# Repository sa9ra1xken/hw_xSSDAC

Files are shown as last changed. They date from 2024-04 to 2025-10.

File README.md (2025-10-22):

ver20230811
https://youtube.com/shorts/RJUZ4uOECH0?feature=share

This is a KiCad project for an experimental implementation of a digital audio device that features an XMOS xCORE embedded processor.
The board is intended to behave as a USB audio class output device (USB DAC), or an audio media player (Micro SD card player). 
Please refer to [project Wiki page](https://github.com/sa9ra1xken/hw_xSSDAC/wiki) for more detailed information.

# Development Environment
KiCad7.0. 

### Software project
Software (executable on xCORE-200) for this project is released here (https://github.com/sa9ra1xken/sw_xSSDAC).

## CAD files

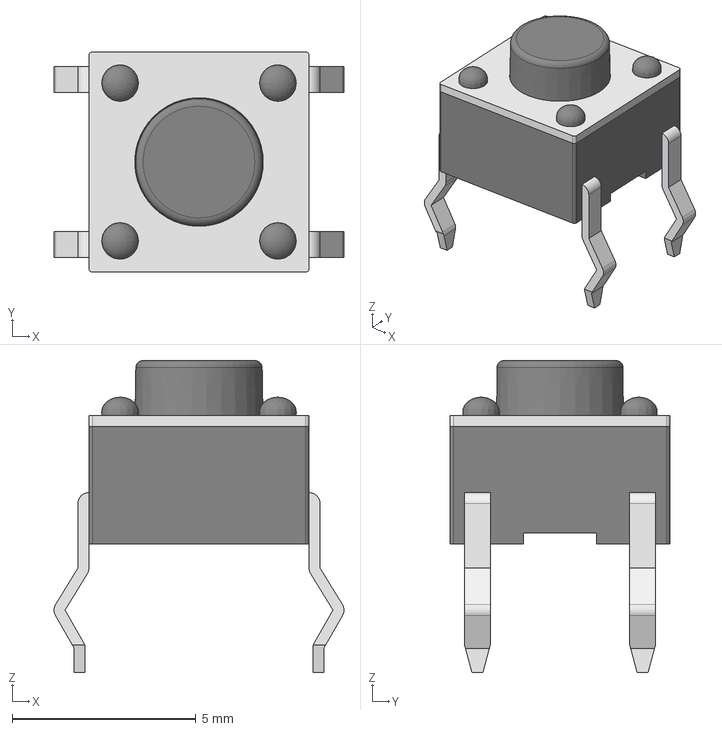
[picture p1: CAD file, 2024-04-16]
pretty/DTS-62N-V.stp
7.90 x 6.00 x 8.50 mm

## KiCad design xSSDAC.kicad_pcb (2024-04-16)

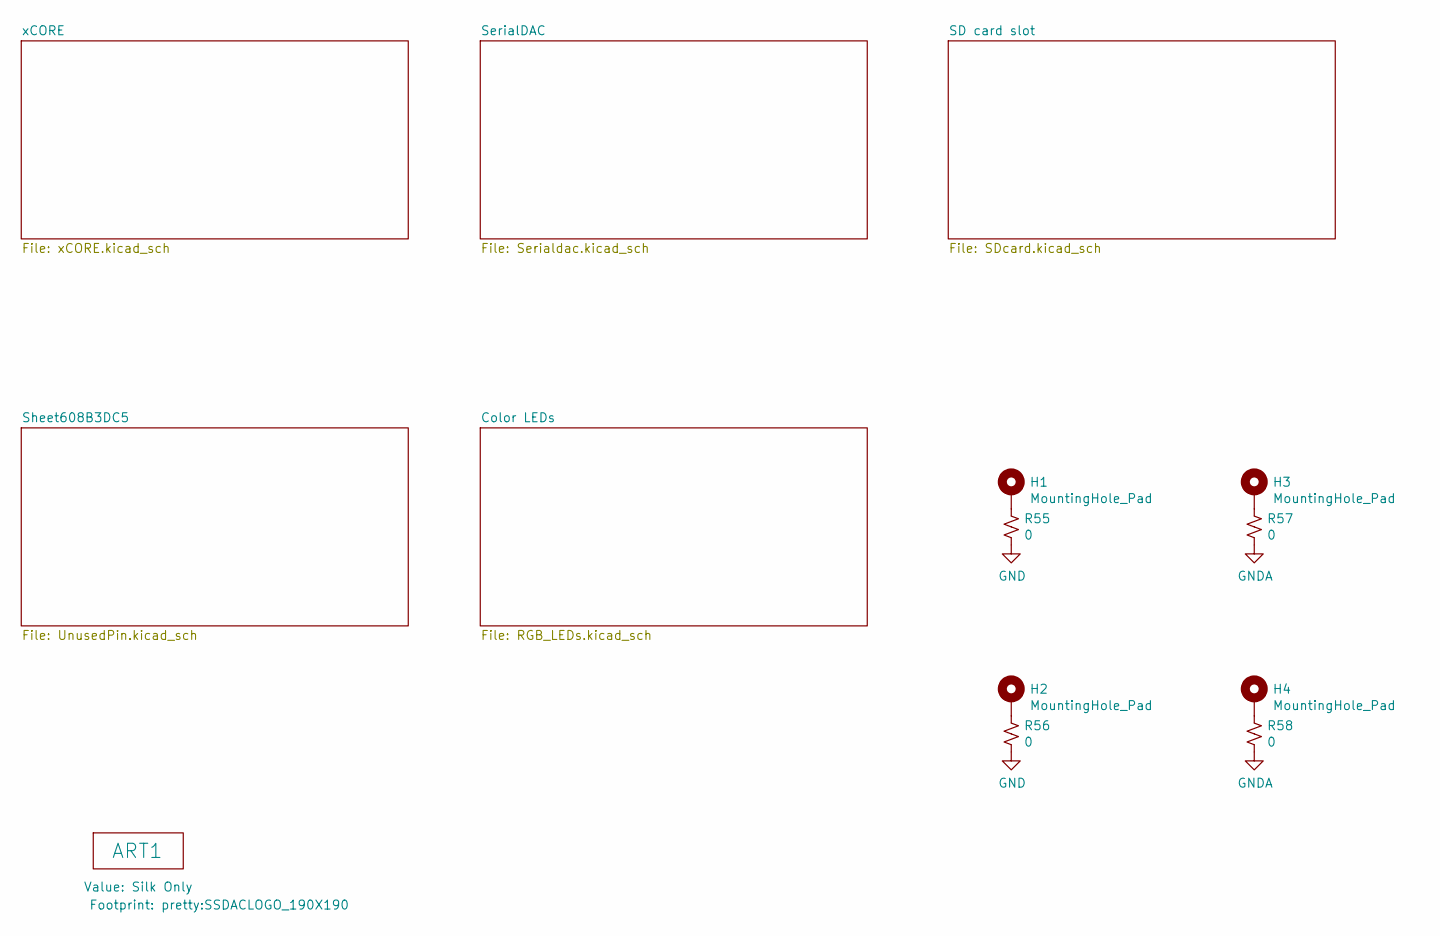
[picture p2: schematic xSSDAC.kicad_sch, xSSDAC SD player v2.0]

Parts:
ART1: Silk Only; SSDACLOGO_190X190
H1, H2, H3, H4: MountingHole_Pad; MountingHole_2.7mm_Pad_Via
R55, R56, R57, R58: 0; R_0603_1608Metric_Pad0.98x0.95mm_HandSolder

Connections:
GNDA: R57.2, R58.2; also elsewhere on the board
unnamed: H1.1, R55.1
unnamed: H2.1, R56.1
unnamed: H3.1, R57.1
unnamed: H4.1, R58.1

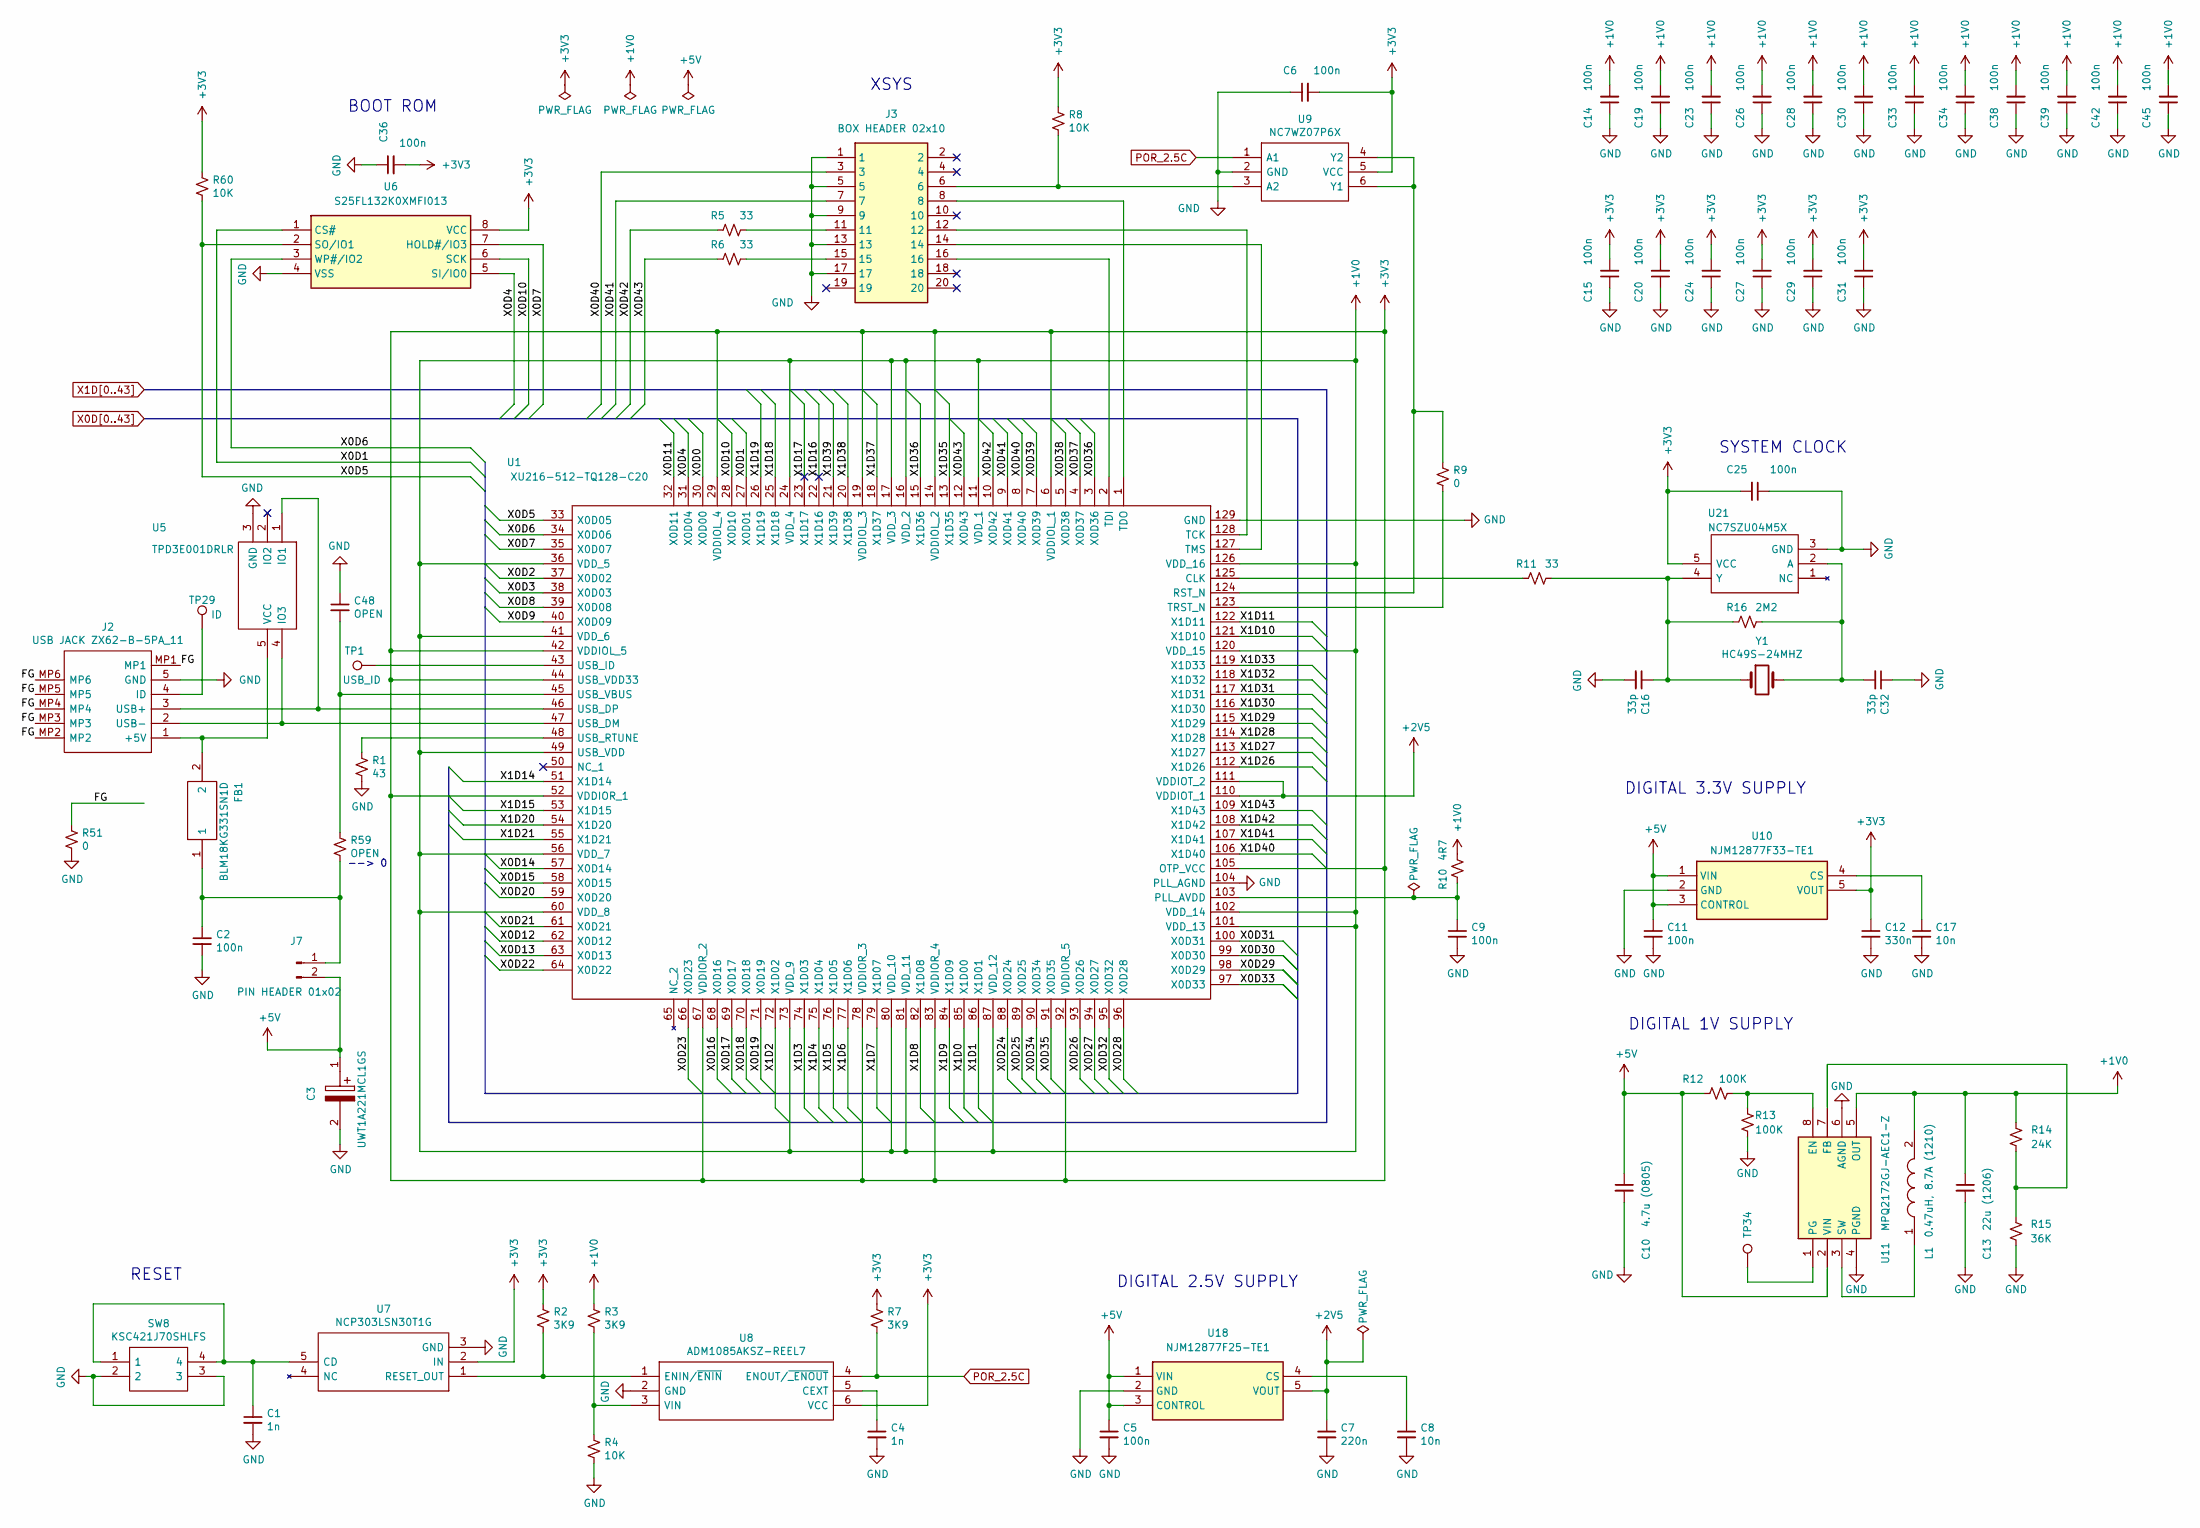
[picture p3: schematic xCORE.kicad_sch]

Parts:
C1, C4: 1n; C_0603_1608Metric_Pad1.08x0.95mm_HandSolder
C2, C5, C6, C9, C11, C14, C15, C19, C20, C23, C24, C25, C26, C27, C28, C29, C30, C31, C33, C34, C36, C38, C39, C42, C45: 100n; C_0603_1608Metric_Pad1.08x0.95mm_HandSolder
C3: UWT1A221MCL1GS; CP_Elec_6.3x7.7; Manufacturer_Part_Number UWT1A221MCL1GS; Mouser Part Number 647-UWT1A221MCL1GS
C7: 220n; C_0603_1608Metric_Pad1.08x0.95mm_HandSolder
C8, C17: 10n; C_0603_1608Metric_Pad1.08x0.95mm_HandSolder
C10: 4.7u (0805); C_0805_2012Metric_Pad1.18x1.45mm_HandSolder
C12: 330n; C_0603_1608Metric_Pad1.08x0.95mm_HandSolder
C13: 22u (1206); C_1206_3216Metric_Pad1.33x1.80mm_HandSolder
C16, C32: 33p; C_0603_1608Metric_Pad1.08x0.95mm_HandSolder
C48: OPEN; C_0603_1608Metric_Pad1.08x0.95mm_HandSolder
FB1: BLM18KG331SN1D; BEADC1608X95N; Manufacturer_Part_Number BLM18KG331SN1D; Mouser Part Number 81-BLM18KG331SN1D
J2: USB JACK ZX62-B-5PA_11; ZX62B5PA; Mouser Part Number 798-ZX62-B-5PA11
J3: BOX HEADER 02x10; SHDRRA20W66P254_2X10_3289X986X927P; Manufacturer_Part_Number 5103310-5; Mouser Part Number 571-5103310-5
J7: PIN HEADER 01x02; PinHeader_1x02_P2.54mm_Vertical
L1: 0.47uH, 8.7A (1210); L_1210_3225Metric_Pad1.42x2.65mm_HandSolder; Manufacturer_Part_Number DFE32CAHR47MR0; Mouser Part Number 963-NR10050T4R9N
R1: 43; R_0603_1608Metric_Pad0.98x0.95mm_HandSolder
R2, R3, R7: 3K9; R_0603_1608Metric_Pad0.98x0.95mm_HandSolder
R4, R8, R60: 10K; R_0603_1608Metric_Pad0.98x0.95mm_HandSolder
R5, R6, R11: 33; R_0603_1608Metric_Pad0.98x0.95mm_HandSolder
R9, R51: 0; R_0603_1608Metric_Pad0.98x0.95mm_HandSolder
R10: 4R7; R_0603_1608Metric_Pad0.98x0.95mm_HandSolder
R12, R13: 100K; R_0603_1608Metric_Pad0.98x0.95mm_HandSolder
R14: 24K; R_0603_1608Metric_Pad0.98x0.95mm_HandSolder
R15: 36K; R_0603_1608Metric_Pad0.98x0.95mm_HandSolder
R16: 2M2; R_0603_1608Metric_Pad0.98x0.95mm_HandSolder
R59: OPEN; R_0603_1608Metric_Pad0.98x0.95mm_HandSolder
SW8: KSC421J70SHLFS; KSC401G50SHLFS; Manufacturer_Part_Number KSC421J70SHLFS; Mouser Part Number 611-KSC421J70SHLFS
TP1: USB_ID; TestPoint_Pad_D1.0mm_noCrtYd
TP29: ID; TestPoint_Pad_D1.0mm_noCrtYd
TP34: TestPoint; TestPoint_Pad_D1.0mm_noCrtYd
U1: XU216-512-TQ128-C20; QFP40P1600X1600X120-129N-D; Manufacturer_Part_Number XU216-512-TQ128-C20; DigiKey Part Number 880-1118-ND
U5: TPD3E001DRLR; SOTFL50P160X60-5N; Mouser Part Number 595-TPD3E001DRLR
U6: S25FL132K0XMFI013; SOIC127P800X216-8N; Manufacturer_Part_Number S25FL132K0XMFI013
U7: NCP303LSN30T1G; SOT95P280X145-5N; Manufacturer_Part_Number NCP303LSN30T1G; Mouser Part Number 863-NCP303LSN30T1G
U8: ADM1085AKSZ-REEL7; SOT65P210X110-6N; Manufacturer_Part_Number ADM1085AKSZ-REEL7; Mouser Part Number 584-ADM1085AKSZ-R7
U9: NC7WZ07P6X; SOT65P210X110-6N; Manufacturer_Part_Number NC7WZ07P6X; Mouser Part Number 512-NC7WZ07P6X
U10: NJM12877F33-TE1; SOT-23-5_HandSoldering; Manufacturer_Part_Number NJM12877F33-TE1; Mouser Part Number 513-NJM12877F33-TE1
U11: MPQ2172GJ-AEC1-Z; MPQ2172GJAEC1Z; Manufacturer_Part_Number MPQ2172GJ-AEC1-Z
U18: NJM12877F25-TE1; SOT-23-5_HandSoldering; Manufacturer_Part_Number NJM12877F33-TE1; Mouser Part Number 513-NJM12877F33-TE1
U21: NC7SZU04M5X; SOT95P280X145-5N; Manufacturer_Part_Number NC7SZU04M5X; Mouser Part Number 512-NC7SZU04M5X
Y1: HC49S-24MHZ; Crystal_HC49-U_Vertical; Manufacturer_Part_Number HC49/U-S24000000ABJB

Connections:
+2V5: C7.1, U1.110 (VDDIOT_1), U1.111 (VDDIOT_2), U18.5 (VOUT)
/xCORE/FG: J2.MP1, J2.MP2, J2.MP3, J2.MP4, J2.MP5, J2.MP6, R51.1
unnamed: FB1.2, J2.1 (+5V), U5.5 (VCC)
unnamed: J2.4 (ID), TP29.1
unnamed: J2.3 (USB+), U1.46 (USB_DP), U5.1 (IO1)
unnamed: J2.2 (USB-), U1.47 (USB_DM), U5.4 (IO3)
unnamed: J3.11, R5.1
unnamed: J3.15, R6.1
unnamed: C2.1, FB1.1, J7.1, R59.2
unnamed: R11.2, U1.125 (CLK)
unnamed: C9.1, R10.2, U1.103 (PLL_AVDD)
unnamed: R9.1, U1.124 (RST_N), U9.4 (Y2), U9.6 (Y1)
unnamed: J3.12, U1.128 (TCK)
unnamed: J3.16, U1.2 (TDI)
unnamed: J3.8, U1.1 (TDO)
unnamed: J3.14, U1.127 (TMS)
unnamed: R9.2, U1.123 (TRST_N)
unnamed: TP1.1, U1.43 (USB_ID)
unnamed: R1.1, U1.48 (USB_RTUNE)
unnamed: C48.2, R59.1, U1.45 (USB_VBUS)
unnamed: C1.1, SW8.1, SW8.4, U7.5 (CD)
unnamed: R2.2, U7.1 (RESET_OUT), U8.1 (ENIN/~ENIN)
unnamed: C4.1, U8.5 (CEXT)
unnamed: R3.2, R4.1, U8.3 (VIN)
unnamed: J3.6, R8.2, U9.3 (A2)
unnamed: C17.1, U10.4 (CS)
unnamed: R12.2, R13.2, U11.8 (EN)
unnamed: R14.2, R15.2, U11.7 (FB)
unnamed: L1.1, U11.3 (SW)
unnamed: C8.1, U18.4 (CS)
unnamed: C32.2, R16.1, U21.2 (A), Y1.2
unnamed: C16.1, R11.1, R16.2, U21.4 (Y), Y1.1
POR_2.5C: R7.2, U8.4 (ENOUT/~_ENOUT), U9.1 (A1)
X0D0: U1.30 (X0D00); also elsewhere on the board
X0D1: U1.27 (X0D01), U6.1 (CS#)
X0D2: U1.37 (X0D02); also elsewhere on the board
X0D3: U1.38 (X0D03); also elsewhere on the board
X0D4: U1.31 (X0D04), U6.5 (SI/IO0)
X0D5: R60.2, U1.33 (X0D05), U6.2 (SO/IO1)
X0D6: U1.34 (X0D06), U6.3 (WP#/IO2)
X0D7: U1.35 (X0D07), U6.7 (HOLD#/IO3)
X0D8: U1.39 (X0D08); also elsewhere on the board
X0D9: U1.40 (X0D09); also elsewhere on the board
X0D10: U1.28 (X0D10), U6.6 (SCK)
X0D11: U1.32 (X0D11); also elsewhere on the board
X0D12: U1.62 (X0D12); also elsewhere on the board
X0D13: U1.63 (X0D13); also elsewhere on the board
X0D14: U1.57 (X0D14); also elsewhere on the board
X0D15: U1.58 (X0D15); also elsewhere on the board
X0D16: U1.68 (X0D16); also elsewhere on the board
X0D17: U1.69 (X0D17); also elsewhere on the board
X0D18: U1.70 (X0D18); also elsewhere on the board
X0D19: U1.71 (X0D19); also elsewhere on the board
X0D20: U1.59 (X0D20); also elsewhere on the board
X0D21: U1.61 (X0D21); also elsewhere on the board
X0D22: U1.64 (X0D22); also elsewhere on the board
X0D23: U1.66 (X0D23); also elsewhere on the board
X0D26: U1.93 (X0D26); also elsewhere on the board
X0D27: U1.94 (X0D27); also elsewhere on the board
X0D28: U1.96 (X0D28); also elsewhere on the board
X0D29: U1.98 (X0D29); also elsewhere on the board
X0D30: U1.99 (X0D30); also elsewhere on the board
X0D31: U1.100 (X0D31); also elsewhere on the board
X0D32: U1.95 (X0D32); also elsewhere on the board
X0D33: U1.97 (X0D33); also elsewhere on the board
X0D34: U1.90 (X0D34); also elsewhere on the board
X0D35: U1.91 (X0D35); also elsewhere on the board
X0D36: U1.3 (X0D36); also elsewhere on the board
X0D37: U1.4 (X0D37); also elsewhere on the board
X0D38: U1.5 (X0D38); also elsewhere on the board
X0D39: U1.7 (X0D39); also elsewhere on the board
X0D40: J3.3, U1.8 (X0D40)
X0D41: J3.7, U1.9 (X0D41)
X0D42: R5.2, U1.10 (X0D42)
X0D43: R6.2, U1.12 (X0D43)
X1D0: U1.85 (X1D00); also elsewhere on the board
X1D1: U1.86 (X1D01); also elsewhere on the board
X1D2: U1.72 (X1D02); also elsewhere on the board
X1D3: U1.74 (X1D03); also elsewhere on the board
X1D4: U1.75 (X1D04); also elsewhere on the board
X1D5: U1.76 (X1D05)
X1D6: U1.77 (X1D06)
X1D7: U1.79 (X1D07)
X1D8: U1.82 (X1D08); also elsewhere on the board
X1D9: U1.84 (X1D09); also elsewhere on the board
X1D10: U1.121 (X1D10); also elsewhere on the board
X1D11: U1.122 (X1D11); also elsewhere on the board
X1D14: U1.51 (X1D14)
X1D15: U1.53 (X1D15)
X1D16: U1.22 (X1D16)
X1D17: U1.23 (X1D17)
X1D18: U1.25 (X1D18)
X1D19: U1.26 (X1D19)
X1D20: U1.54 (X1D20)
X1D21: U1.55 (X1D21)
X1D26: U1.112 (X1D26); also elsewhere on the board
X1D27: U1.113 (X1D27); also elsewhere on the board
X1D28: U1.114 (X1D28); also elsewhere on the board
X1D29: U1.115 (X1D29); also elsewhere on the board
X1D30: U1.116 (X1D30); also elsewhere on the board
X1D31: U1.117 (X1D31); also elsewhere on the board
X1D32: U1.118 (X1D32); also elsewhere on the board
X1D33: U1.119 (X1D33); also elsewhere on the board
X1D35: U1.13 (X1D35); also elsewhere on the board
X1D36: U1.15 (X1D36); also elsewhere on the board
X1D37: U1.18 (X1D37); also elsewhere on the board
X1D38: U1.20 (X1D38); also elsewhere on the board
X1D39: U1.21 (X1D39); also elsewhere on the board
X1D40: U1.106 (X1D40); also elsewhere on the board
X1D41: U1.107 (X1D41); also elsewhere on the board
X1D42: U1.108 (X1D42); also elsewhere on the board
X1D43: U1.109 (X1D43); also elsewhere on the board

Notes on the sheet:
DIGITAL 3.3V SUPPLY
--> 0
DIGITAL 2.5V SUPPLY
XSYS
DIGITAL 1V SUPPLY
BOOT ROM
SYSTEM CLOCK
RESET

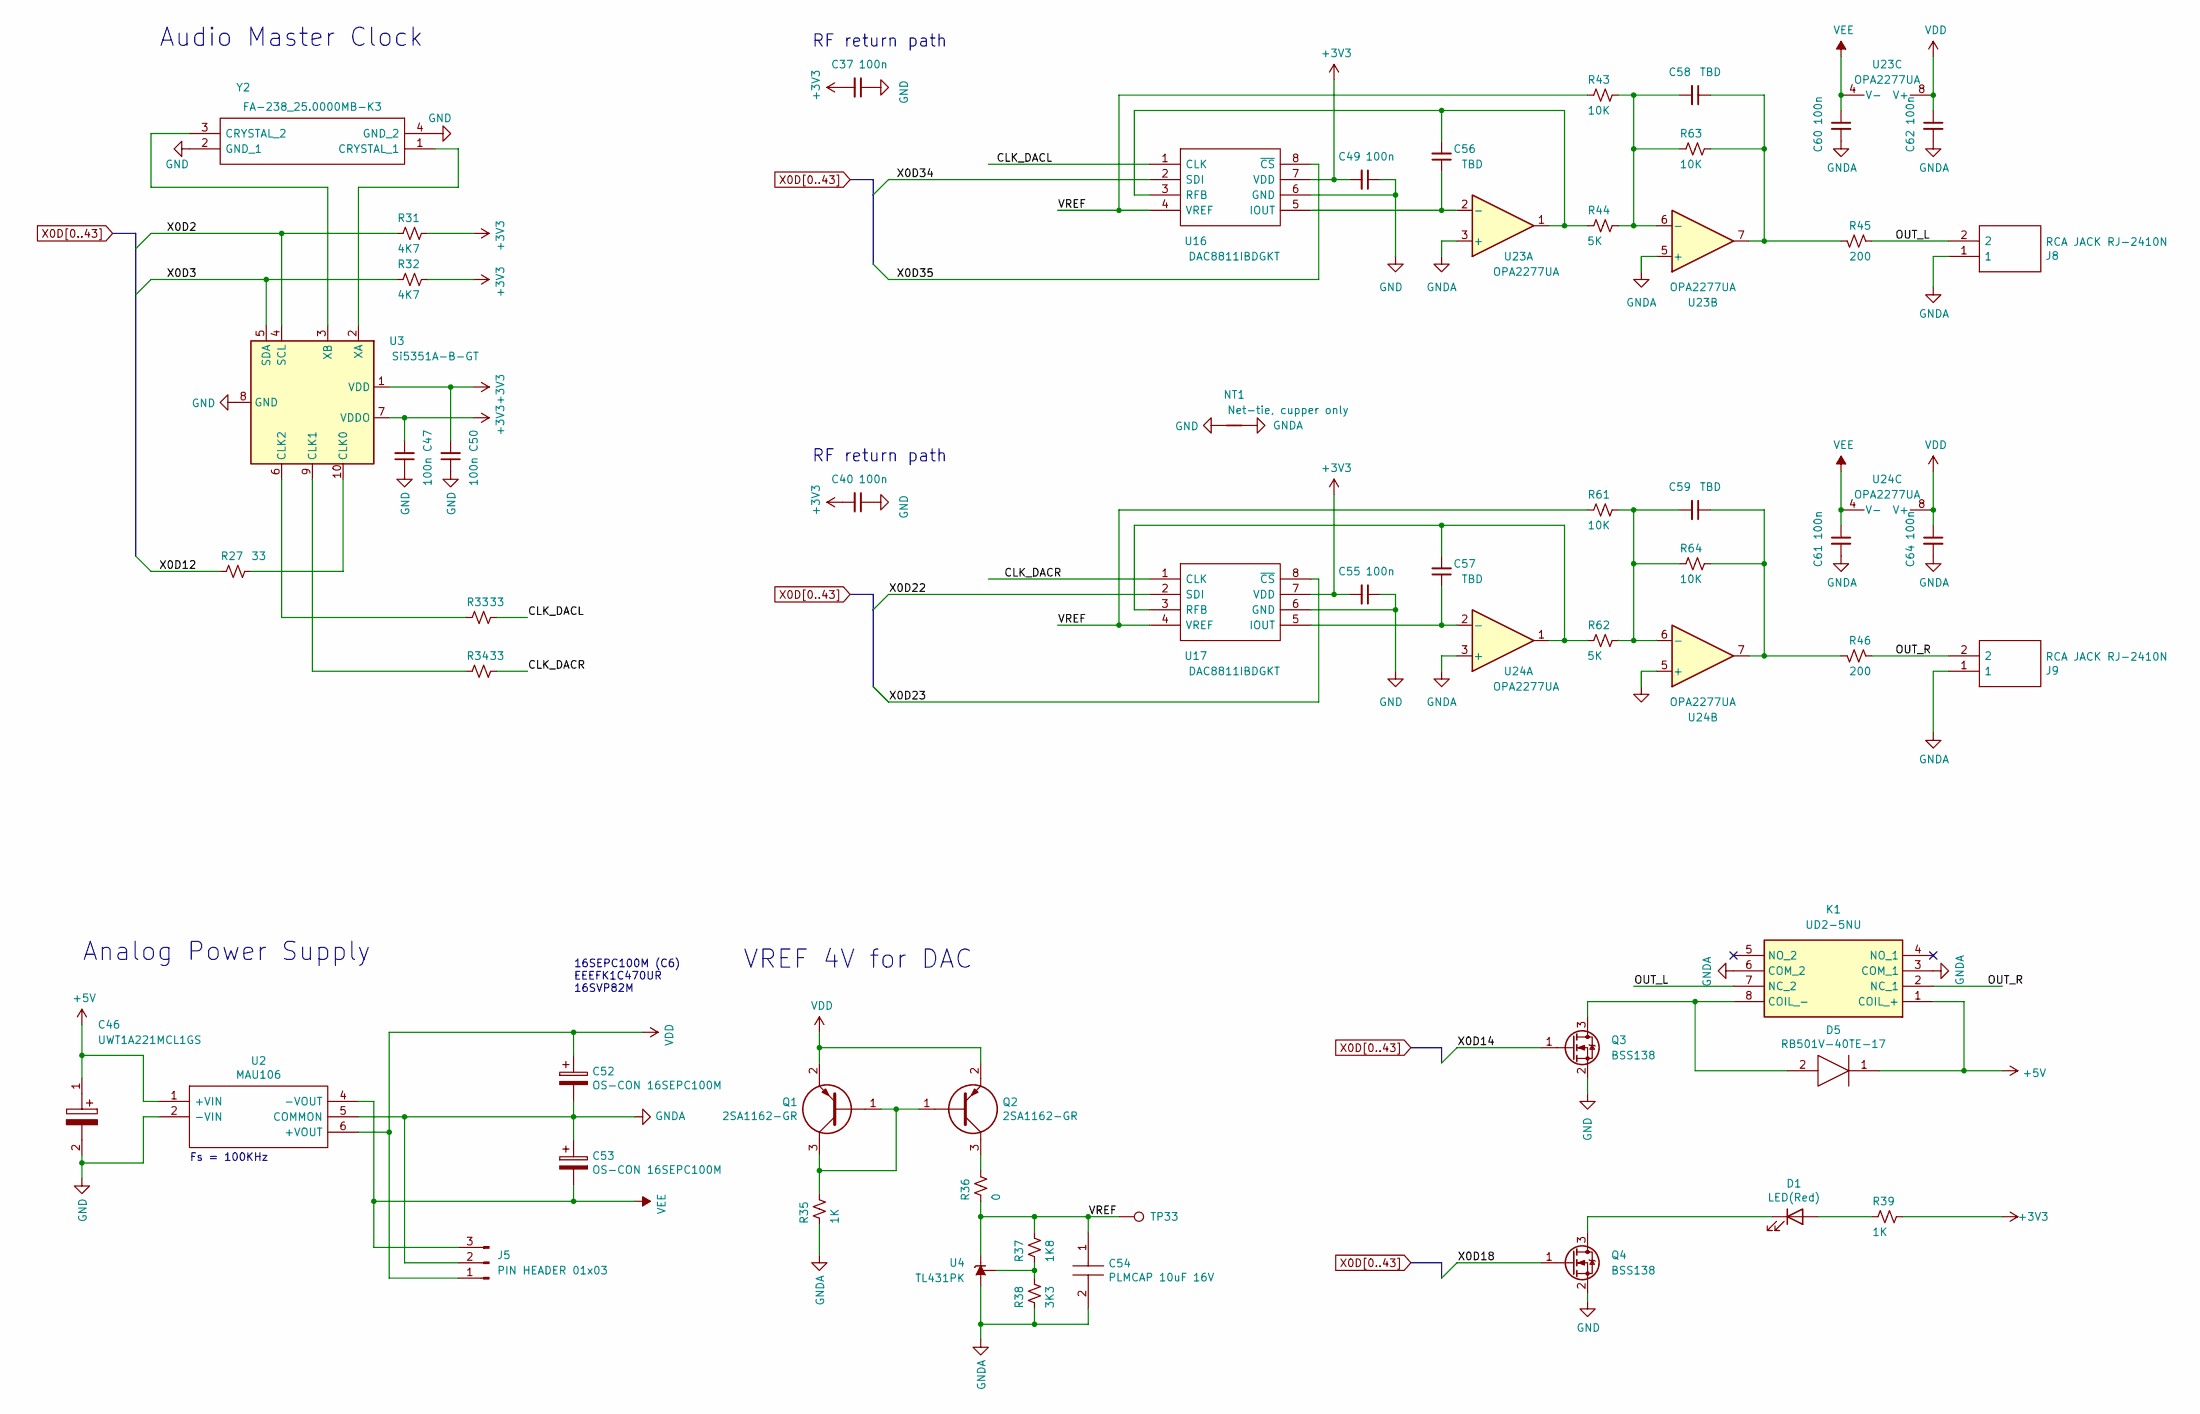
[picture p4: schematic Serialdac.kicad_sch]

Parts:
C37, C40, C47, C49, C50, C55, C60, C61, C62, C64: 100n; C_0603_1608Metric_Pad1.08x0.95mm_HandSolder
C46: UWT1A221MCL1GS; CP_Elec_6.3x7.7; Manufacturer_Part_Number UWT1A221MCL1GS; Mouser Part Number 647-UWT1A221MCL1GS
C52, C53: OS-CON 16SEPC100M; CP_Radial_D6.3mm_P2.50mm; Manufacturer_Part_Number OS-CON 16SEPC100M
C54: PLMCAP 10uF 16V; CAPC4532X280N; Manufacturer_Part_Number 16MU106MC44532; Mouser Part Number 232-16MU106MC44532
C56, C57, C58, C59: TBD; C_Rect_L4.0mm_W2.5mm_P2.50mm
D1: LED(Red); LED_0603_1608Metric_Pad1.05x0.95mm_HandSolder; Manufacturer_Part_Number OSHR1608C1A
D5: RB501V-40TE-17; SODFL2512X90N; Manufacturer_Part_Number RB501V-40TE-17; Mouser Part Number 755-RB501V-40TE-17
J5: PIN HEADER 01x03; PinHeader_1x03_P2.54mm_Vertical
J8, J9: RCA JACK RJ-2410N; RJ2410N; Manufacturer_Part_Number RJ-2410N
K1: UD2-5NU; UD25NUN; Manufacturer_Part_Number UD2-5NU; Mouser Part Number 551-UD2-5NU
NT1: Net-tie, cupper only; NetTie-2_SMD_Pad1.0mm
Q1, Q2: 2SA1162-GR; SC-59; Manufacturer_Part_Number 2SA1162-GR(F)
Q3, Q4: BSS138; SOT-23; Manufacturer_Part_Number BSS138
R27, R33, R34: 33; R_0603_1608Metric_Pad0.98x0.95mm_HandSolder
R31, R32: 4K7; R_0603_1608Metric_Pad0.98x0.95mm_HandSolder
R35, R39: 1K; R_0603_1608Metric_Pad0.98x0.95mm_HandSolder
R36: 0; R_0603_1608Metric_Pad0.98x0.95mm_HandSolder
R37: 1K8; R_0603_1608Metric_Pad0.98x0.95mm_HandSolder
R38: 3K3; R_0603_1608Metric_Pad0.98x0.95mm_HandSolder
R43, R61, R63, R64: 10K; R_Axial_DIN0204_L3.6mm_D1.6mm_P2.54mm_Vertical
R44, R62: 5K; R_Axial_DIN0204_L3.6mm_D1.6mm_P2.54mm_Vertical
R45, R46: 200; R_Axial_DIN0204_L3.6mm_D1.6mm_P2.54mm_Vertical
TP33: TestPoint; TestPoint_Pad_3.0x3.0mm
U2: MAU106; MAU109; Manufacturer_Part_Number MAU106
U3: Si5351A-B-GT; SOP50P490X110-10N; Manufacturer_Part_Number Si5351A-B-GT
U4: TL431PK; SOT-89-3; Manufacturer_Part_Number TA76431F
U16, U17: DAC8811IBDGKT; TSSOP-8_3x3mm_P0.65mm; Manufacturer_Part_Number DAC8811IBDGKT
U23, U24: OPA2277UA; SOIC-8_3.9x4.9mm_P1.27mm; Manufacturer_Part_Number OPA2277UA
Y2: FA-238_25.0000MB-K3; EPSON-FA-238; Manufacturer_Part_Number FA-238 25.0000MB-K3; Mouser Part Number 732-FA238-25B-K3

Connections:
/SerialDAC/CLK_DACL: R33.1, U16.1 (CLK)
/SerialDAC/CLK_DACR: R34.1, U17.1 (CLK)
/SerialDAC/OUT_L: J8.2, K1.7 (NC_2), R45.2
/SerialDAC/OUT_R: J9.2, K1.2 (NC_1), R46.2
GNDA: C52.2, C53.1, C54.2, C60.2, C61.2, C62.2, C64.2, J5.2, J8.1, J9.1, K1.3 (COM_1), K1.6 (COM_2), NT1.2, R35.2, R38.2, U2.5 (COMMON), U4.2 (A), U23.3 (+), U23.5 (+), U24.3 (+), U24.5 (+); also elsewhere on the board
unnamed: C58.1, R45.1, R63.2, U23.7
unnamed: C59.1, R46.1, R64.2, U24.7
unnamed: D5.2, K1.8 (COIL_-), Q3.3 (D)
unnamed: Q1.1, Q1.3, Q2.1, R35.1
unnamed: Q2.3, R36.1
unnamed: R27.1, U3.10 (CLK0)
unnamed: R34.2, U3.9 (CLK1)
unnamed: R33.2, U3.6 (CLK2)
unnamed: U3.2 (XA), Y2.1 (CRYSTAL_1)
unnamed: U3.3 (XB), Y2.3 (CRYSTAL_2)
unnamed: R37.2, R38.1, U4.1 (REF)
unnamed: C56.1, U16.5 (IOUT), U23.2 (-)
unnamed: C56.2, R44.1, U16.3 (RFB), U23.1
unnamed: C57.1, U17.5 (IOUT), U24.2 (-)
unnamed: C57.2, R62.1, U17.3 (RFB), U24.1
unnamed: C58.2, R43.2, R44.2, R63.1, U23.6 (-)
unnamed: C59.2, R61.2, R62.2, R64.1, U24.6 (-)
VDD: C52.1, C62.1, C64.1, J5.1, Q1.2, Q2.2, U2.6 (+VOUT), U23.8 (V+), U24.8 (V+)
VEE: C53.2, C60.1, C61.1, J5.3, U2.4 (-VOUT), U23.4 (V-), U24.4 (V-)
X0D2: R31.2, U3.4 (SCL); also elsewhere on the board
X0D3: R32.2, U3.5 (SDA); also elsewhere on the board
X0D12: R27.2; also elsewhere on the board
X0D14: Q3.1 (G); also elsewhere on the board
X0D22: U17.2 (SDI); also elsewhere on the board
X0D23: U17.8 (~CS); also elsewhere on the board
X0D34: U16.2 (SDI); also elsewhere on the board
X0D35: U16.8 (~CS); also elsewhere on the board

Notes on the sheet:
Fs = 100KHz
RF return path
VREF 4V for DAC
16SEPC100M (C6) EEEFK1C470UR 16SVP82M
Analog Power Supply
Audio Master Clock

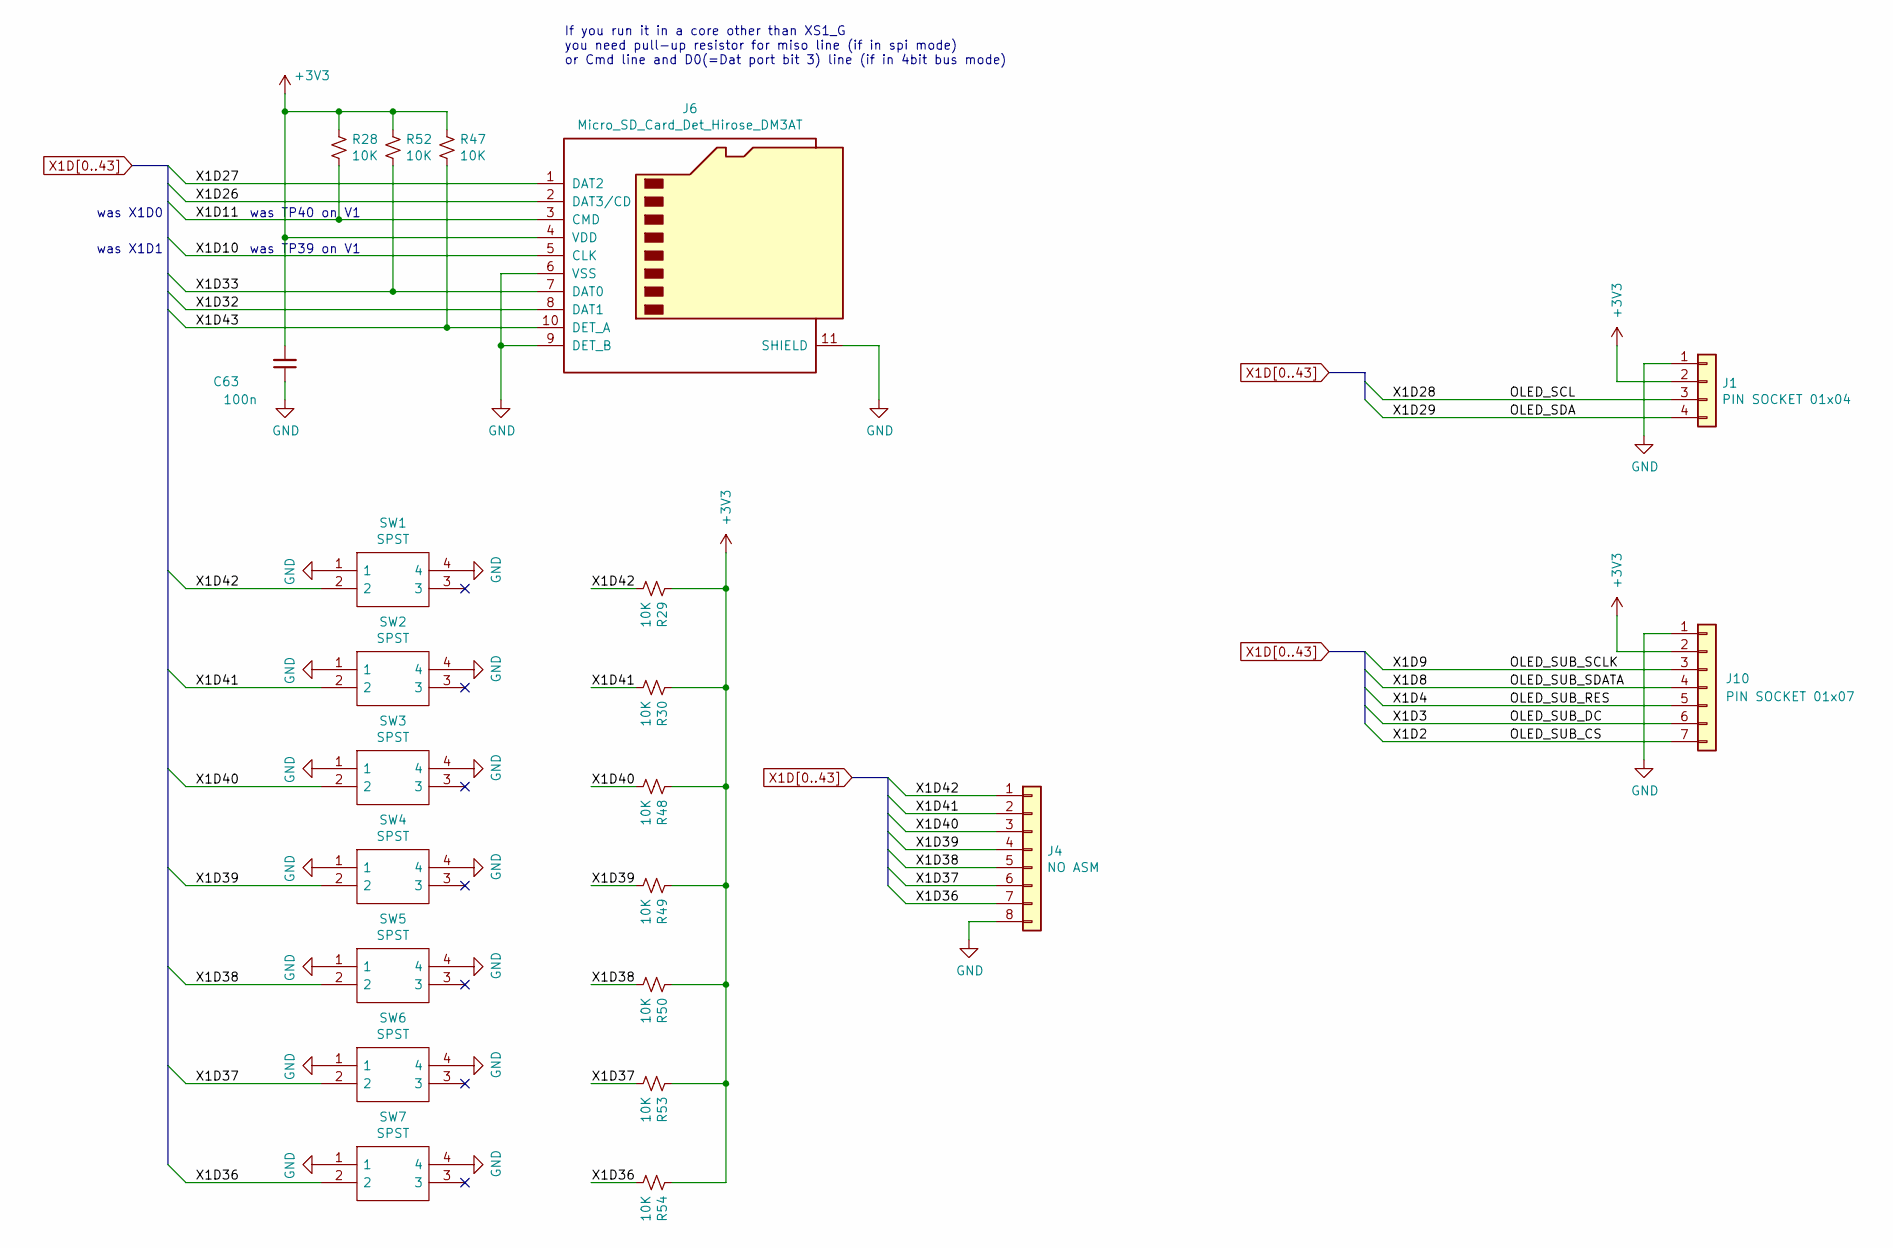
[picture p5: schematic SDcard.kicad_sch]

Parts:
C63: 100n; C_0603_1608Metric_Pad1.08x0.95mm_HandSolder
J1: PIN SOCKET 01x04; OLED_4pin_1.3_128X64
J4: NO ASM; PinHeader_1x08_P2.54mm_Vertical
J6: Micro_SD_Card_Det_Hirose_DM3AT; Hirose_DM3AT-SF-PEJM5
J10: PIN SOCKET 01x07; OLED_7pin_0.95_96X64_RGB
R28, R29, R30, R47, R48, R49, R50, R52, R53, R54: 10K; R_0603_1608Metric_Pad0.98x0.95mm_HandSolder
SW1, SW4, SW7: SPST; TS-0606; Manufacturer_Part_Number DTS-63-N-V-RED
SW2, SW3, SW5, SW6: SPST; TS-0606; Manufacturer_Part_Number DTS-63-N-V-WHT

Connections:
X1D2: J10.7; also elsewhere on the board
X1D3: J10.6; also elsewhere on the board
X1D4: J10.5; also elsewhere on the board
X1D8: J10.4; also elsewhere on the board
X1D9: J10.3; also elsewhere on the board
X1D10: J6.5 (CLK); also elsewhere on the board
X1D11: J6.3 (CMD), R28.2; also elsewhere on the board
X1D26: J6.2 (DAT3/CD); also elsewhere on the board
X1D27: J6.1 (DAT2); also elsewhere on the board
X1D28: J1.3; also elsewhere on the board
X1D29: J1.4; also elsewhere on the board
X1D32: J6.8 (DAT1); also elsewhere on the board
X1D33: J6.7 (DAT0), R52.2; also elsewhere on the board
X1D36: J4.7, R54.2, SW7.2; also elsewhere on the board
X1D37: J4.6, R53.2, SW6.2; also elsewhere on the board
X1D38: J4.5, R50.2, SW5.2; also elsewhere on the board
X1D39: J4.4, R49.2, SW4.2; also elsewhere on the board
X1D40: J4.3, R48.2, SW3.2; also elsewhere on the board
X1D41: J4.2, R30.2, SW2.2; also elsewhere on the board
X1D42: J4.1, R29.2, SW1.2; also elsewhere on the board
X1D43: J6.10 (DET_A), R47.2; also elsewhere on the board

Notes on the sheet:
was X1D0
was X1D1
was TP40 on V1
was TP39 on V1
If you run it in a core other than XS1_G you need pull-up resistor for miso line (if in spi mode) or Cmd line and D0(=Dat port bit 3) line (if in 4bit bus mode)

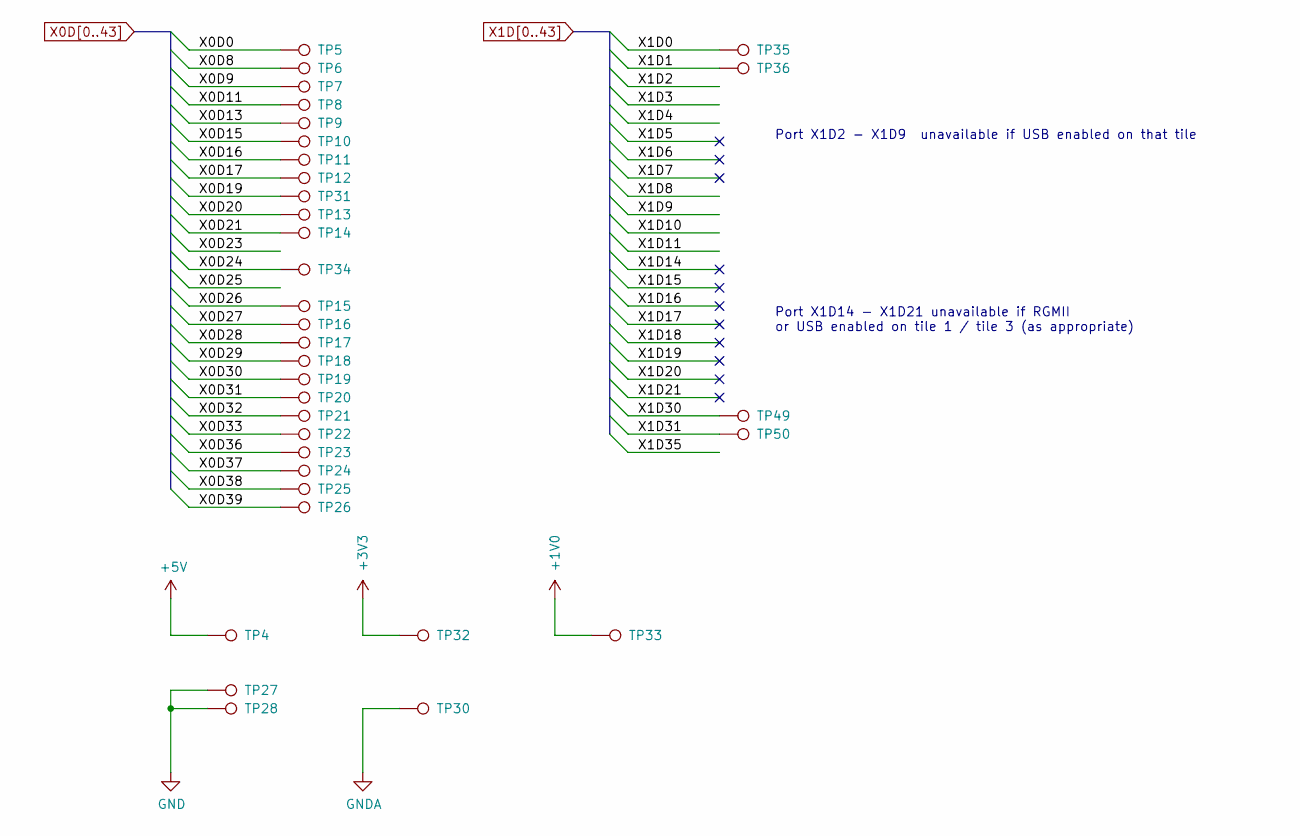
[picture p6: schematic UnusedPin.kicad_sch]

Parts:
TP4, TP27, TP28, TP30, TP32, TP33: TestPoint; TestPoint_Pad_3.0x3.0mm
TP5, TP6, TP7, TP8, TP9, TP10, TP11, TP12, TP13, TP14, TP15, TP16, TP17, TP18, TP19, TP20, TP21, TP22, TP23, TP24, TP25, TP26, TP31, TP34, TP35, TP36, TP49, TP50: TestPoint; TestPoint_Pad_D1.0mm_noCrtYd

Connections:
GNDA: TP30.1; also elsewhere on the board
X0D0: TP5.1; also elsewhere on the board
X0D8: TP6.1; also elsewhere on the board
X0D9: TP7.1; also elsewhere on the board
X0D11: TP8.1; also elsewhere on the board
X0D13: TP9.1; also elsewhere on the board
X0D15: TP10.1; also elsewhere on the board
X0D16: TP11.1; also elsewhere on the board
X0D17: TP12.1; also elsewhere on the board
X0D19: TP31.1; also elsewhere on the board
X0D20: TP13.1; also elsewhere on the board
X0D21: TP14.1; also elsewhere on the board
X0D26: TP15.1; also elsewhere on the board
X0D27: TP16.1; also elsewhere on the board
X0D28: TP17.1; also elsewhere on the board
X0D29: TP18.1; also elsewhere on the board
X0D30: TP19.1; also elsewhere on the board
X0D31: TP20.1; also elsewhere on the board
X0D32: TP21.1; also elsewhere on the board
X0D33: TP22.1; also elsewhere on the board
X0D36: TP23.1; also elsewhere on the board
X0D37: TP24.1; also elsewhere on the board
X0D38: TP25.1; also elsewhere on the board
X0D39: TP26.1; also elsewhere on the board
X1D0: TP35.1; also elsewhere on the board
X1D1: TP36.1; also elsewhere on the board
X1D30: TP49.1; also elsewhere on the board
X1D31: TP50.1; also elsewhere on the board

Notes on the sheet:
Port X1D2 - X1D9 unavailable if USB enabled on that tile
Port X1D14 - X1D21 unavailable if RGMII or USB enabled on tile 1 / tile 3 (as appropriate)

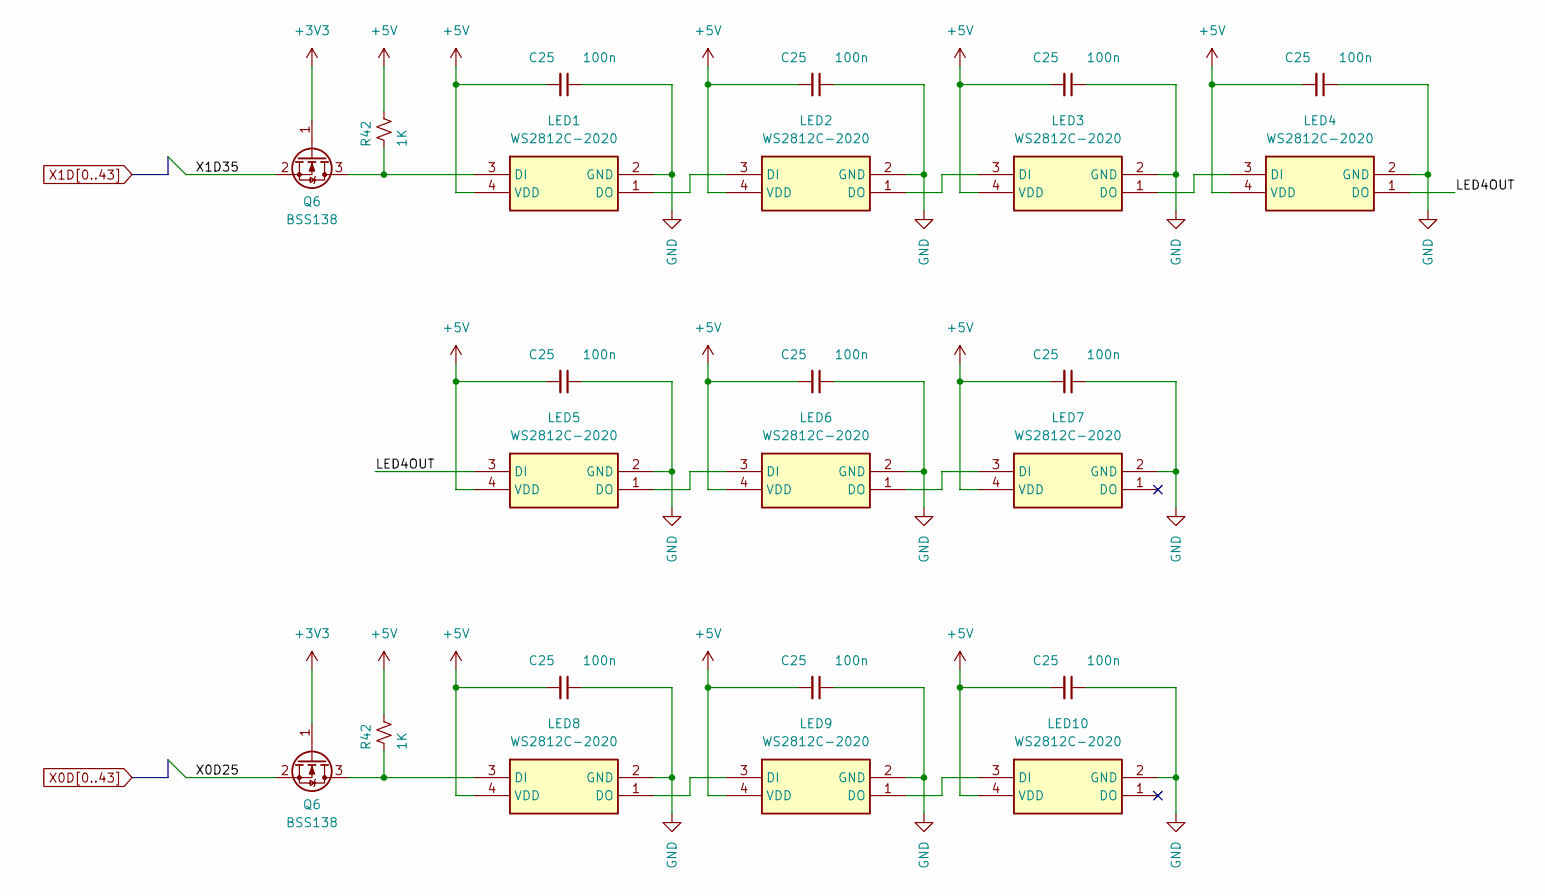
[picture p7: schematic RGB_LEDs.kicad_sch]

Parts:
C25: 100n; C_0603_1608Metric_Pad1.08x0.95mm_HandSolder
LED1, LED2, LED3, LED4, LED5, LED6, LED7, LED8, LED9, LED10: WS2812C-2020; WS2812C2020; Manufacturer_Part_Number WS2812C-2020
Q6: BSS138; SOT-23; Manufacturer_Part_Number BSS138
R42: 1K; R_0603_1608Metric_Pad0.98x0.95mm_HandSolder

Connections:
/Color LEDs/LED4OUT: LED4.1 (DO), LED5.3 (DI)
unnamed: LED1.1 (DO), LED2.3 (DI)
unnamed: LED2.1 (DO), LED3.3 (DI)
unnamed: LED3.1 (DO), LED4.3 (DI)
unnamed: LED5.1 (DO), LED6.3 (DI)
unnamed: LED6.1 (DO), LED7.3 (DI)
unnamed: LED8.1 (DO), LED9.3 (DI)
unnamed: LED9.1 (DO), LED10.3 (DI)
X0D18: Q6.1 (G); also elsewhere on the board

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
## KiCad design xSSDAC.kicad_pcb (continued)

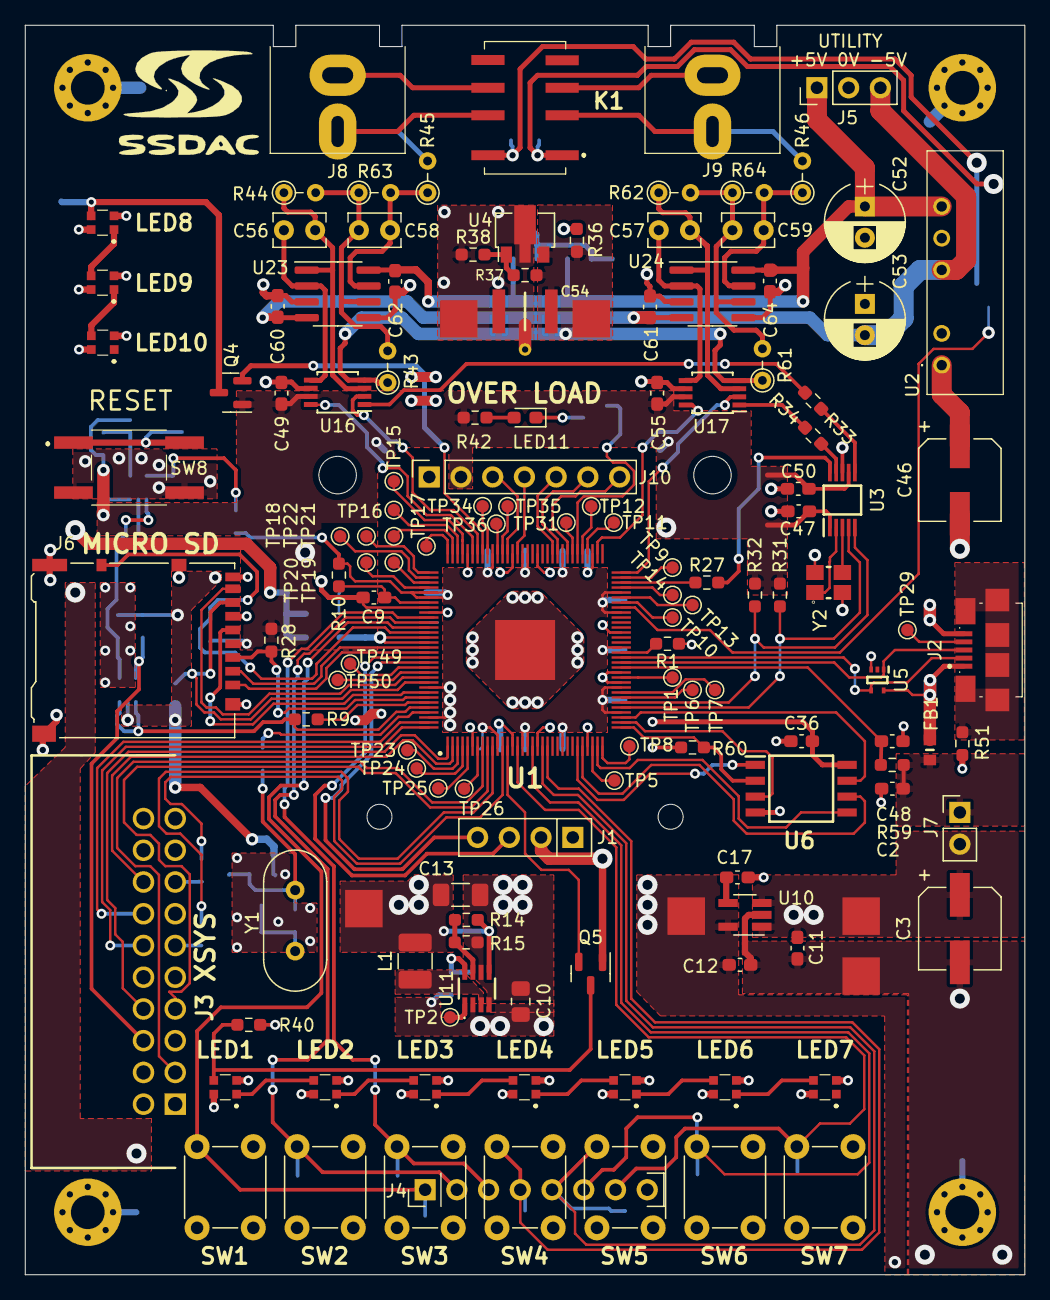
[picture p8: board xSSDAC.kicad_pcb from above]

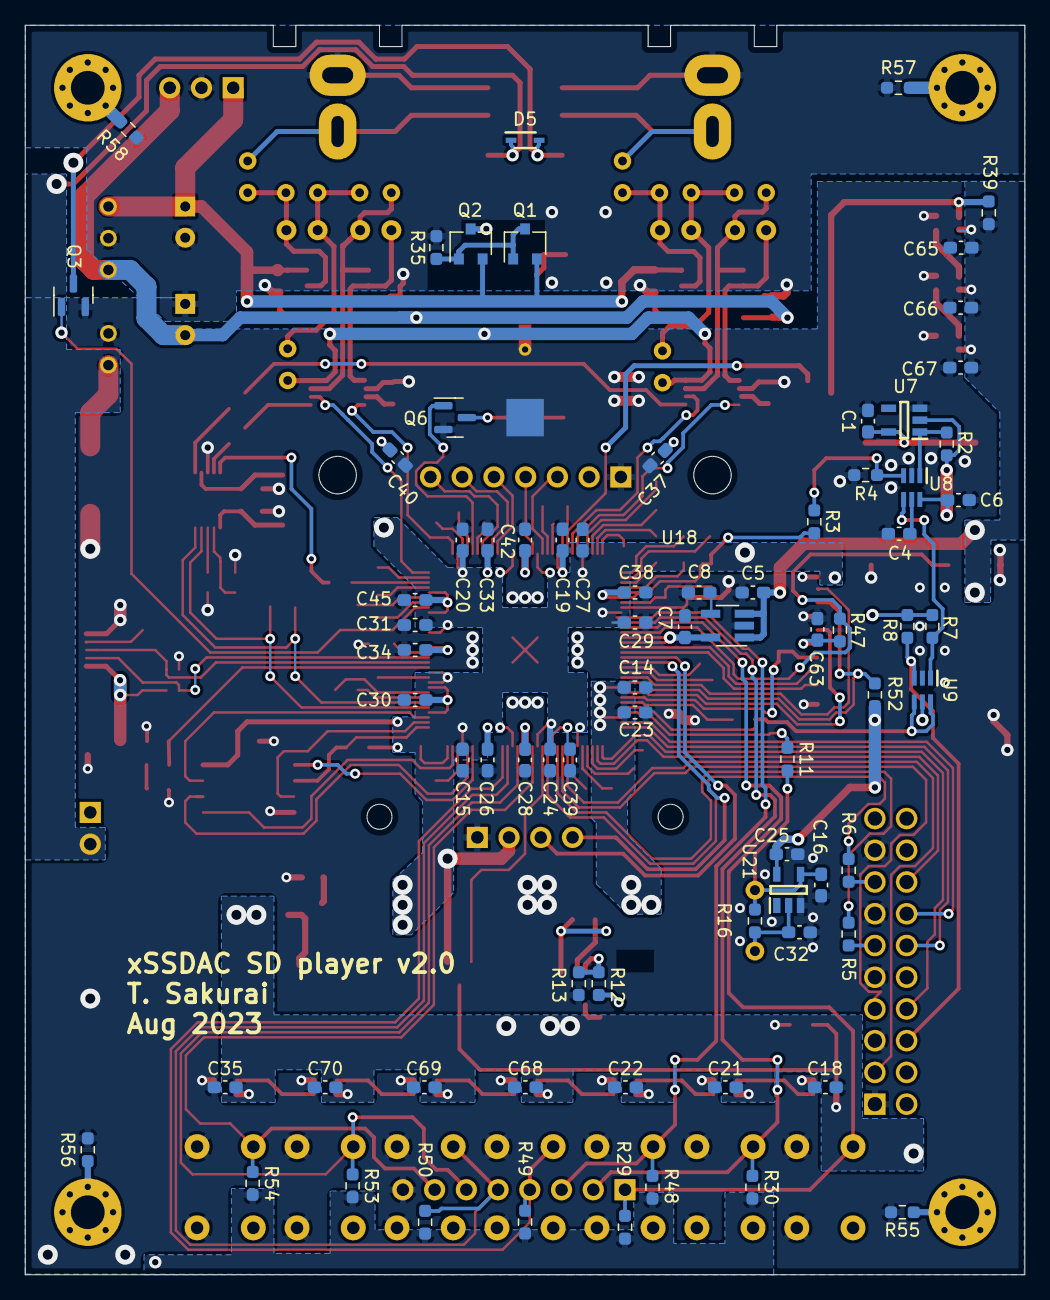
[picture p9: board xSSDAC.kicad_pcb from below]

Board: 2 copper layers, 80.0 x 100.0 mm, 221 parts (77 on the bottom side), 149 nets.

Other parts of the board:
C18, C21, C22, C35, C65, C66, C67, C68, C69, C70: 100n; C_0603_1608Metric_Pad1.08x0.95mm_HandSolder
LED11: LED(Red); LED_0603_1608Metric_Pad1.05x0.95mm_HandSolder
Q5: BSS138; SOT-23
R40: 1K; R_0603_1608Metric_Pad0.98x0.95mm_HandSolder
TP2: TestPoint; TestPoint_Pad_D1.0mm_noCrtYd
TP3: TestPoint; TestPoint_Pad_3.0x3.0mm

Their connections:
X1D35: Q5.2 (S); also elsewhere on the board

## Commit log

2024-04-28 removed unudrf folder
    [xSSdAUGHTER-JK-B_Cu.gbl, xSSdAUGHTER-JK-B_Mask.gbs, xSSdAUGHTER-JK-Edge_Cuts.gm1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]
2024-04-28 port map added
    port map added
    [Port_map.ods]
2025-10-22 house keep
    [Port_map.ods]
